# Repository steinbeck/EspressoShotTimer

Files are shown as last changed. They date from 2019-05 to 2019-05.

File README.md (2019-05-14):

# EspressoShotTimer
Tuning your espresso machine so that it provides the best espresso possible is as much an art as it can be science and engineering. 
Apart from many other parameters (pressure, temperature), the time for the pulling the shot is crucial. Too short and you underextract, to long and the shot may become bitter or diluted. Many coffee wikis and forums homed in on 30 seconds as a good time for a pulling a good shot. I personally also found this to be a good guideline. I use 7 to 8 grams of freshly ground espresso, and tune the degree of grinding as well as the pressure to provide 30 seconds of shot time. Of course I want regular control that my shot time is indeed in this range, so an espress shot timer is needed. 

So, this project is about building an Espresso Shot Timer for the Gaggia Classic and it covers electronics, software and a 3D printed enclosure for the timer. 

* TODO in this section:
** Add picture of final build attached to Gaggia and counting :)

## Boundary conditions

The timer, counting seconds, should start when you push the button engaging the pressure pump and obviously stop when you switch the pump off again. It would be ideal if the final value could be displayed for some more seconds after the pump is switched off, but this is not part of my design for reasons that will become obvious (mostly because if would have been complicated). 

## Electronics
The electronics should provide a timer counting seconds and a display to display the current value. The switch that switches the pump of the Gaggia on and off is switching 230V, so one needs a power supply to convert the 230V down to the 3.3V needed by the electronics of this project. 

SAFETY WARNING: If you work on projects like this that deal with mains voltage of 110V or higher, you need to know what you are doing. Otherwise you may shock or kill yourself and even others trying to help you. If you unsure, ask someone who knows! 

Since I was doing microcontroller programming with the Arduino framework a lot recently, I decided to go for something that was simple for me, rather than the cheapest and overall simplest solution. So I based the design on an ESP8266 and OLED display. The ESP8266 is mostly wasted here, because it provides Wifi which is not needed here, but I like the modular design of the WEMOS D1 componentent with ESP8266 and went to those. You can quite likely find something even cheaper. 
So, the main component of this build were

* Wemos D1 compatible ESP8266 board for 6.30 Euro (bought from AZ-Delivery via Amazon.de)
* D1 compatible OLED shield for 4.50 Euro from HomeEngineer (bought via Amazon.de)
* Power supply 230V to 3.3.V from TenStar (bought from AZ-Delivery via Amazon.de)
* A circuit board with some wire, capacitors and fuses

The board design was inspired by [this RandomeNerd tutorial](https://randomnerdtutorials.com/esp8266-hi-link-hlk-pm03/), which convinced me to add fuses to protect the components and some capacitors to stablize the current to the microcontroller. You can probably do without those and safe some space. As you will see, these additional component made the whole timer quite bulky :).

TODO: I just realised that it would be much smarter to separate OLED/ESP8266 from the power supply and leave the power supply in its own enclosure within the Gaggia case. That leaves us with only 3.3V lines and a much smaller display enclosure outside of the Gaggia :)

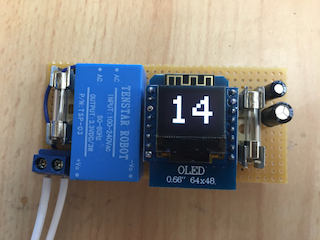
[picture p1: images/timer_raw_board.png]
Picture of electronics circuit board without enclosure Electronics circuit board


* TODO in this section:
** Add Fritzing wiring diagram

## Software
The very basic software for the ESP8266 is based on a ticker which increments the seconds counter and calls the update of the OLED. 
It needs the Adafruit_GFX library and the Adafruit library for the SSD1306 to handle the low level communication with the hardware. 
You further need the ticker library. The file EspressoShotTimer.ino from this project should compile without issues if you pre-install all libraries listed in the beginning of this file. 

## Enclosure
The enclosure was designed in OpenSCAD (https://www.openscad.org/) to be 3D printed. OpenSCAD allows for parametric design of 3D components, i.e. you code your model rather than using a point and click GUI. I could never find the patience to learn these point and click user interfaces. 
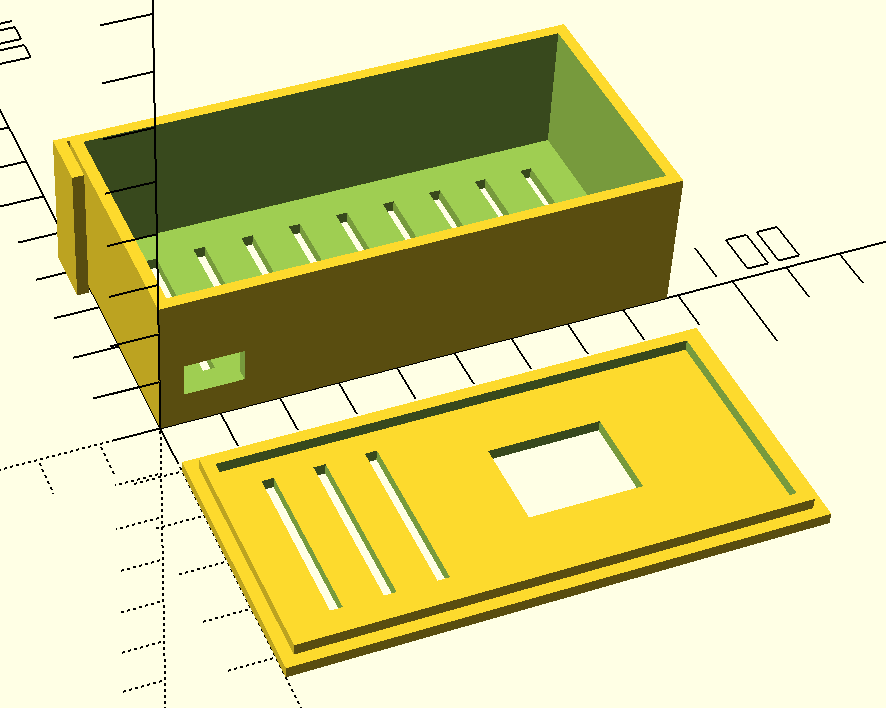
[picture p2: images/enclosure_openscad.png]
Enclosure as shown in openSCAD Enclosure as diplayed during design in OpenSCAD


* TODO in this section:
** Add picture of 3D printed enclosure

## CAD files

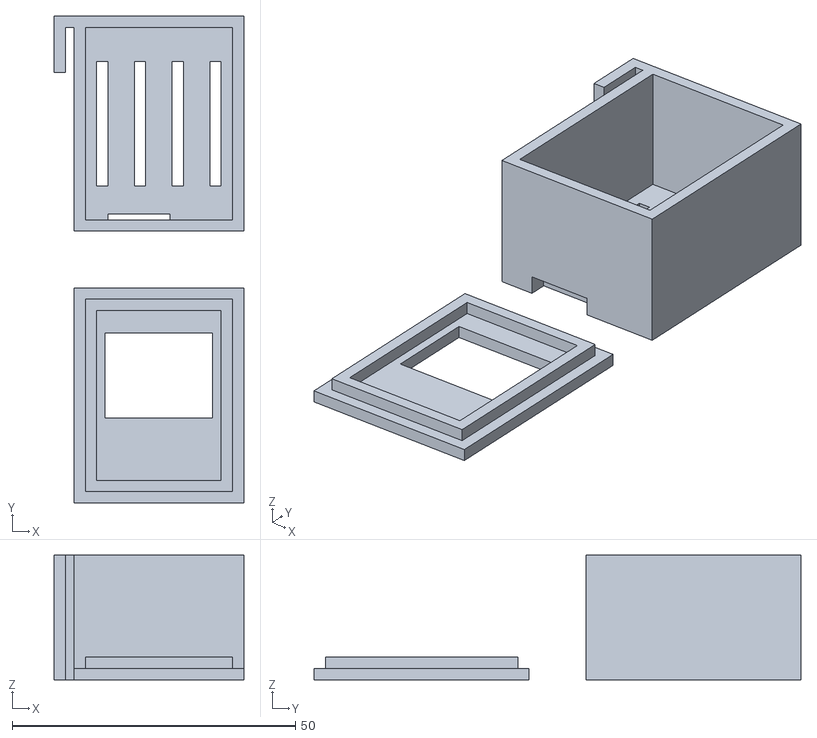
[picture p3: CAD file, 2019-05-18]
EspressoShotTimer_OLED_Case.stl
33.5 x 86.0 x 22.0

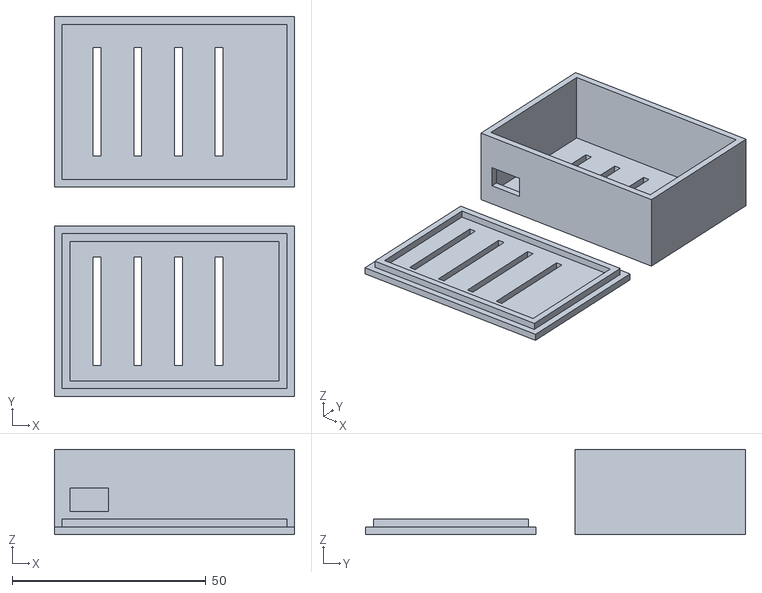
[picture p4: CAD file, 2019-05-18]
EspressoShotTimer.stl
62.0 x 98.0 x 22.0

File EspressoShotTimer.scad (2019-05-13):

wall_thickness = 2;
base_width = 88;
base_depth = 44;
case_height = 25;
gaggia_steel_thickness = 0.5;
slitcount = 8;
slitwidth = 2;


/*
*   Definition of body. 
*/

module base()
{
  cube([base_width,base_depth, case_height]);
}

module interior()
{
  cube([base_width-4,base_depth-4,case_height]);
}

module base_block() {
  difference() {
    base();
    translate([wall_thickness,wall_thickness,wall_thickness])
        interior();
  }
}

module bottom_slits() {    
    gap = ((base_width - (10 * wall_thickness) - (slitcount*slitwidth))) / slitcount;
    for (i = [0:8]){
       translate([(5*wall_thickness)+(i*(gap+slitwidth)), (4 * wall_thickness), -1])
       cube([2, base_depth - (8 * wall_thickness), wall_thickness + 2]);
    }
}

module cable_inlet()
{
    cube([10,4,6]);
}

module slitted_lower_part()
{
    difference(){
        base_block();
        bottom_slits();
        }
}

module hook()
{
    translate([-gaggia_steel_thickness, base_depth - 1, 0])
    {
        cube([gaggia_steel_thickness, 1, case_height]);
    }
    translate([-gaggia_steel_thickness - wall_thickness, base_depth - 10, 0])
    {
        cube([wall_thickness, 10, case_height]);
    }

}



module complete_lower_part()
{
    difference(){
        slitted_lower_part();
        translate([4,-1,6])
        {
            cable_inlet();
        }
    }
}

/*
* Lid definition starts here
*/

module lid_body()
{

        cube([base_width,base_depth, wall_thickness]);
}


module top_slits() {    
    gap = ((base_width - (10 * wall_thickness) - (slitcount*slitwidth))) / slitcount;
    for (i = [0:2]){
       translate([(5*wall_thickness)+(i*(gap+slitwidth)), (4 * wall_thickness), -1])
       cube([2, base_depth - (8 * wall_thickness), wall_thickness + 2]);
    }
}

module display_window()
{
    cube([19,15,5]);
}

module snap_frame()
{
    difference(){
        cube([base_width - wall_thickness*2,base_depth  - wall_thickness*2, wall_thickness]);
        translate([wall_thickness, wall_thickness, -1]){   
            cube([base_width - wall_thickness*4,base_depth  - wall_thickness*4, wall_thickness +2]);
        }
    }
}


module lid()
{
    difference()
    {
        difference()
        {
            lid_body();
              translate([43+wall_thickness, 13+wall_thickness, -1])
            {   
                display_window();
            }
     
        }
        top_slits();
    }
    translate([wall_thickness, wall_thickness, wall_thickness])
    {
        snap_frame();
    }
}

//slits();

complete_lower_part();

translate([0, -base_depth - 10, 0])
{
    lid();
}

hook();

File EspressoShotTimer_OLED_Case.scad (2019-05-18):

wall_thickness = 2;
base_width = 30;
base_depth = 38;
case_height = 22;

gaggia_steel_thickness = 1.5;
hook_height = 8;



slit_count = 4;
slit_width = 2;

display_width = 19;
display_depth = 15;
 // this should be equal to wall_thickness
 // but this leads to artifacts in openSCAD display
 // so we make it a bit thicker
display_height = 4;

display_window_offset_x=3.5;
display_window_offset_y=13;

/*
*   Definition of body. 
*/

module base()
{
  cube([base_width,base_depth, case_height]);
}

module interior()
{
  cube([base_width-4,base_depth-4,case_height]);
}

module base_block() {
  difference() {
    base();
    translate([wall_thickness,wall_thickness,wall_thickness])
        interior();
  }
}

module bottom_slits() {    
    gap = ((base_width - (4 * wall_thickness) - (slit_count*slit_width))) / (slit_count -1);
    echo(gap);
    for (i = [0:slit_count - 1]){
       echo(i*(gap+slit_width));
       translate([(2*wall_thickness)+(i*(gap+slit_width)), (4 * wall_thickness), -1])
       cube([2, base_depth - (8 * wall_thickness), wall_thickness + 2]);
    }
}

module cable_inlet()
{
    cube([11,4,3]);
}

module slitted_lower_part()
{
    difference(){
        base_block();
        bottom_slits();
        }
}

module hook()
{
    translate([-gaggia_steel_thickness, base_depth - wall_thickness, 0])
    {
        cube([gaggia_steel_thickness, wall_thickness, case_height]);
    }
    translate([-gaggia_steel_thickness - wall_thickness, base_depth - 10, 0])
    {
        cube([wall_thickness, hook_height+wall_thickness, case_height]);
    }

}



module complete_lower_part()
{
    difference(){
        slitted_lower_part();
        translate([6,-1,0])
        {
            cable_inlet();
        }
    }
}

/*
* Lid definition starts here
*/

module lid_body()
{

        cube([base_width,base_depth, wall_thickness]);
}


module top_slits() {    
    gap = ((base_width - (4 * wall_thickness) - (slitcount*slitwidth))) / slitcount;
    for (i = [0:2]){
       translate([(2*wall_thickness)+(i*(gap+slitwidth)), (4 * wall_thickness), -1])
       cube([2, base_depth - (8 * wall_thickness), wall_thickness + 2]);
    }
}

module display_window()
{
    cube([display_width,display_depth,display_height]);
}

module snap_frame()
{
    difference(){
        cube([base_width - wall_thickness*2,base_depth  - wall_thickness*2, wall_thickness]);
        translate([wall_thickness, wall_thickness, -1]){   
            cube([base_width - wall_thickness*4,base_depth  - wall_thickness*4, wall_thickness +2]);
        }
    }
}


module lid()
{
        difference()
        {
            lid_body();
              translate([display_window_offset_x+wall_thickness, display_window_offset_y+wall_thickness, -1])
            {   
                display_window();
            }
     
        }

    translate([wall_thickness, wall_thickness, wall_thickness])
    {
        snap_frame();
    }
}

slits();

complete_lower_part();

translate([0, -base_depth - 10, 0])
{
    lid();
}


hook();

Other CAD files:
EspressoShotTimer_Power_Supply.scad

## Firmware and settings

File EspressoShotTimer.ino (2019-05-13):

/*********************************************************************
This code is for a 64x48 size  
Monochrome OLEDs based on SSD1306 drivers
using I2C to communicate
3 pins are required to interface (2 I2C and one reset)

Written by Christoph Steinbeck, 
MIT License
*********************************************************************/

#include <SPI.h>
#include <Wire.h>
#include <Ticker.h>
#include <time.h>
#include <Adafruit_GFX.h>
#include <Adafruit_SSD1306.h>

// SCL GPIO5
// SDA GPIO4
#define OLED_RESET 0  // GPIO0
Adafruit_SSD1306 display(OLED_RESET);

Ticker ticker1;
int seconds = 0;

void setup()   {
  Serial.begin(9600);


  display.begin(SSD1306_SWITCHCAPVCC, 0x3C);  // initialize with the I2C addr 0x3C (for the 64x48)
 
 /* Start a 1 second ticker which calls the routine displayNumber() below, which again increments the 
 *  seconds counter and updates the OLED display
 */ 
 ticker1.attach(1, displayNumber);

}

void loop() {
  delay(100);
}

void displayNumber()
{
  char secondsChar[3];
  seconds = seconds + 1;
  if (seconds > 99) seconds = 0; 
  // Clear the buffer.
  display.clearDisplay();
  display.setTextSize(5);
  display.setTextColor(WHITE);
  
  String secondsString = String(seconds);
  if (seconds < 10) secondsString = "0" + secondsString;
  secondsString.toCharArray(secondsChar, 3);
  int16_t tbx, tby; uint16_t tbw, tbh;
  display.getTextBounds(secondsChar, 0, 0, &tbx, &tby, &tbw, &tbh);
  uint16_t x = (display.width() - tbw) / 2 + 2;
  uint16_t y = (display.height() - tbh) / 2;
  display.setCursor(x,y);
  display.println(secondsChar);
  display.display();
  
}

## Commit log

2019-05-13 First version of 3D model for enclosure written in OpenSCAD
    [EspressoShotTimer.scad]
2019-05-13 First commit of the ESP8266 code for the timer.
2019-05-13 Added warning on mains voltage
    Added warning on mains voltage and further information
2019-05-13 Added picture of raw circuit board
2019-05-13 Added hook to clip to Gaggia case
    [EspressoShotTimer.scad]
2019-05-13 corrected hook position
    [EspressoShotTimer.scad]
2019-05-14 Added an idea to separate display from power supply
2019-05-18 Added various new 3D printint parts
    [EspressoShotTimer.stl, EspressoShotTimer_OLED_Case.scad, EspressoShotTimer_OLED_Case.stl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]
